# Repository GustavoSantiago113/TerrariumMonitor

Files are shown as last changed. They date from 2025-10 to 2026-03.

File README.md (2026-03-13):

<div align="center">

# 🌱 Tree Seedling Monitor

**An integration of ESP32-CAM with a custom HTTP API backend and Flutter to monitor tree seedling growth.**

</div>



---

## 📜 Table of Contents

- [🌱 Tree Seedling Monitor](#-tree-seedling-monitor)
  - [📜 Table of Contents](#-table-of-contents)
  - [💵 Bill of Materials](#-bill-of-materials)
  - [🎯 Objective](#-objective)
  - [🔗 Workflow](#-workflow)
  - [🔌 ESP32](#-esp32)
    - [⚙️ Configuration](#️-configuration)
    - [🧠 Pseudo-code](#-pseudo-code)
  - [🔙 API Backend](#-api-backend)
    - [🛜 API Endpoint](#-api-endpoint)
    - [🔓 Authentication](#-authentication)
      - [📨 Request Format](#-request-format)
      - [📤 Example Request](#-example-request)
      - [📥 Response](#-response)
      - [📝 Backend Implementation Notes](#-backend-implementation-notes)
  - [📱 App](#-app)
  - [⚡ PCB](#-pcb)
  - [📂 3D Files](#-3d-files)

## 💵 Bill of Materials

| Item | Quantity | Price |
| ---- | --- | ----- |
| Acrilic Case | 1 | 19 |
| Heater | 2 | 3 |
| AHT10 | 1 | 1.5 |
| Exhausting fan | 1 | 5.35 |
| PCB | 1 | 0.4 |
| ESP32CAM | 1 | 17 |
| Purple LED | 1 | 2.5 |
| 3D Printings | 1 | 1 |
| 5V Font | 1 | 5.39 |
| Wires and Connections | Many | 0.26 |
| | **Total** | 55 |

## 🎯 Objective

Build a tree seedling monitoring structure with image and sensor-based data monitoring and environment automation. The image and sensor-based data is sent to a custom HTTP API backend and retrieved by a mobile app. The sensor-based data is used to turn on exhausting fans and LEDs. MOTOR2 is configured as a heater output (see ESP32 section).

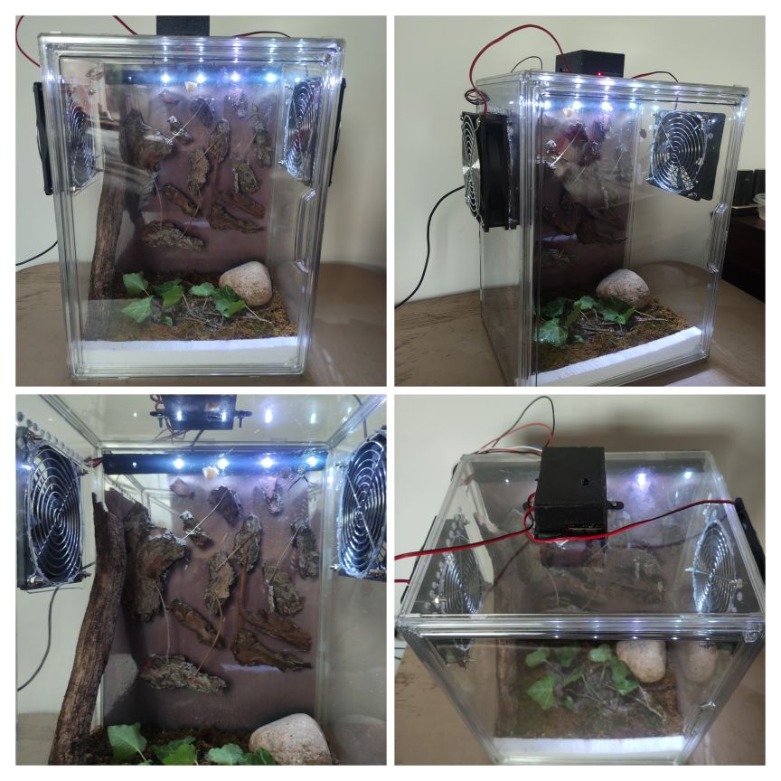
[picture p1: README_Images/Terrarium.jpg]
Terrarium


## 🔗 Workflow

The workflow works as depicted in the picture below.

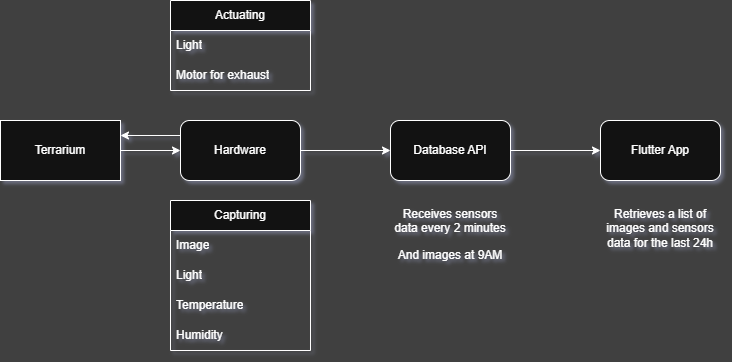
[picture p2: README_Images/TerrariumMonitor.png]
Workflow


The ESP32 captures temperature, air humidity, and light every 2 minutes. If the temperature or humidity exceeds the set threshold, the exhaust fans are activated. If the light is below the set threshold, the LEDs are turned on. After this, the data is sent to a custom HTTP API backend. Every day, at 9 AM and 4 PM, the image is captured, and all the data is uploaded to the backend.

The backend API (running at `********`) receives multipart form data containing:
- Timestamp
- Light intensity (lux)
- Temperature (°C)
- Humidity (%)
- JPEG image file

The API is secured with an API key (`*********` header). The backend stores the images and sensor data, making them available for the mobile app.

A Flutter-based app retrieves the images and sensor-based data from the API and displays it in the screen in form of image and graphs.

## 🔌 ESP32

The final code for the ESP32-CAM is in this [folder](ESP32/terrariumMonitor/). I split the actuators and sensors to make it more organized. All the sensitive information is on `secrets.h` (which I obviously did not push to Git). 

### ⚙️ Configuration

In `secrets.h`, define:
```cpp
#define WIFI_SSID "your_wifi_ssid"
#define WIFI_PASSWORD "your_wifi_password"
```

The API endpoint and key are configured directly in the main sketch:
```cpp
const char* API_ENDPOINT = "***********";
const char* API_KEY_HEADER = "*********";
const char* API_KEY_VALUE = "****************";
```

### 🧠 Pseudo-code

``` bash

INCLUDE required libraries (Arduino, WiFi, HTTPClient, Camera, LittleFS, Sensors)

DEFINE camera pin assignments

CONFIGURE API endpoint and authentication
    - API URL: ***********
    - API Key header: *********
    - API Key value: ****************

SETUP timing variables for periodic data sending (2 minutes)

DECLARE variables for sensor readings (lux, temperature, humidity)

DECLARE function prototypes

FUNCTION setup():
    Start serial communication
    Print startup message
    Test actuators (LEDs and motors)
    Initialize WiFi and wait for connection
    Configure time via NTP
    Initialize camera with optimal settings
    Initialize LittleFS filesystem
    Initialize sensors (light, temperature, humidity)
    Print setup complete

FUNCTION loop():
    IF 2 minutes have passed:
        
        Read sensors (lux, temp, humidity)
        Print sensor values
        Control actuators based on sensor thresholds
        Get current timestamp (via NTP or uptime fallbacks
        Send data to API via HTTP POST multipart/form-data:
            - timestamp
            - lux value
            - temperature value
            - humidity value
        IF upload successful:
            Print success message
        ELSE:
            Print error message
    IF 9 AM or 4 PM:
        Delete previous image file if it exists
        Capture photo and save to LittleFS with timestamp filename
        Send data to API via HTTP POST multipart/form-data:
            - timestamp
            - lux value
            - temperature value
            - humidity value
            - image file (JPEG)
        IF upload successful:
            Delete local image file to free space
            Print success message
        ELSE:
            Print error message
FUNCTION capturePhotoSaveLittleFS(photoPath):
    Flush camera buffer (3 warmup captures)
    Capture photo
    IF capture failed: print error and return
    Print photo file name
    Ensure parent directory exists (create if needed)
    Open file for writing
    IF file open failed: print error and return
    Write photo data to file, flush, and close
    Print file saved message with size
    Verify file exists and size matches written bytes
    IF verification passed: print success
    ELSE: print warning

FUNCTION initLittleFS():
    Mount LittleFS with format option, restart if failed

FUNCTION initWiFi():
    Connect to WiFi with credentials from secrets.h
    Wait for connection, print status and IP address

FUNCTION initCamera():
    Configure camera settings (pins, resolution, quality)
    IF PSRAM detected: use UXGA resolution
    ELSE: use SVGA resolution
    Initialize camera, restart if failed
    Configure sensor parameters (brightness, contrast, exposure, etc.)
    Print camera initialized message

FUNCTION sendDataToAPI(imagePath, lux, temp, humi, timestamp):
    Open image file from LittleFS
    IF file open failed: return false
    Initialize HTTP client with API endpoint
    Add API key header
    Generate random boundary for multipart form data
    Build multipart body with:
        - Form field: timestamp
        - Form field: lux
        - Form field: temperature
        - Form field: humidity
        - Form field: image (binary JPEG data)
    Send HTTP POST request manually:
        - Send headers (Host, *********, Content-Type, Content-Length)
        - Send form fields
        - Stream image file in 512-byte chunks with progress logging
        - Send closing boundary
    Wait for server response (10s timeout)
    Parse HTTP response code
    IF code is 200 or 201: return true (success)
    ELSE: print error and return false

```

## 🔙 API Backend

The system uses a custom HTTP API backend running at `********`.

### 🛜 API Endpoint

**POST** `/api/upload`

### 🔓 Authentication
Requests must include the `*********` header with value: `************************************`

#### 📨 Request Format
Content-Type: `multipart/form-data`

**Form fields:**
- `timestamp` - Unix timestamp of the data collection
- `lux` - Light intensity in lux (float)
- `temperature` - Temperature in Celsius (float)
- `humidity` - Humidity percentage (float)
- `image` - JPEG image file

#### 📤 Example Request
```http
POST /api/upload HTTP/1.1
Host: 10.0.0.50:8080
*********: ************************************
Content-Type: multipart/form-data; boundary=----WebKitFormBoundaryXYZ

------WebKitFormBoundaryXYZ
Content-Disposition: form-data; name="timestamp"

1700000000
------WebKitFormBoundaryXYZ
Content-Disposition: form-data; name="lux"

450.50
------WebKitFormBoundaryXYZ
Content-Disposition: form-data; name="temperature"

24.50
------WebKitFormBoundaryXYZ
Content-Disposition: form-data; name="humidity"

65.30
------WebKitFormBoundaryXYZ
Content-Disposition: form-data; name="image"; filename="1700000000.jpg"
Content-Type: image/jpeg

[binary image data]
------WebKitFormBoundaryXYZ--
```

#### 📥 Response
- **200 OK** or **201 Created** - Data successfully received and stored
- **401 Unauthorized** - Invalid or missing API key
- **400 Bad Request** - Invalid form data

#### 📝 Backend Implementation Notes
The backend should:
- Validate the API key
- Parse multipart form data
- Store images with timestamp-based filenames
- Store sensor readings in a database (linked by timestamp)
- Optionally implement data retention policies (e.g., delete data when the image folder exceeds 10GB)

## 📱 App

The App was made using Flutter and deployed locally. It retrieves all the readings and images from the custom API backend. The last image and data is shown on the screen. All the data is used to plot line graphs. The 8 most recent images are shown on the screen. If the user wants to see more, they click "See More" and 8 more will appear.

The app communicates with the backend API to:
- Retrieve images with their associated timestamps and sensor data
- Display historical data (24h) in graph format

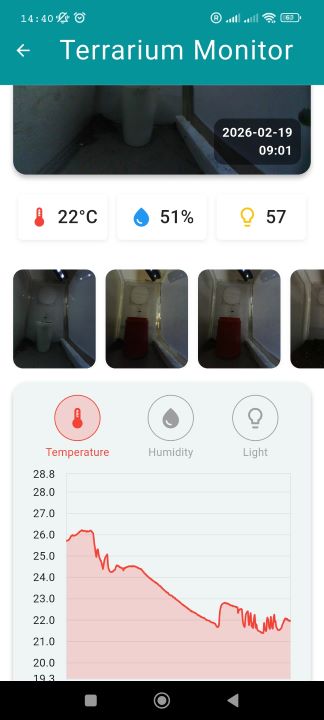
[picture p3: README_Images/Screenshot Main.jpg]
Main Page


When clicking on past images, the image will pop-up and be shown bigger on the screen, with the Date and Time, and data measured at the same time.

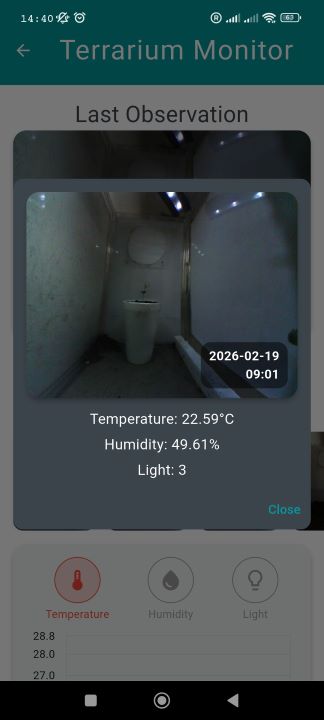
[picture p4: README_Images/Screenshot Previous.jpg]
Previous Data


## ⚡ PCB

Under the [PCB](PCB) folder, you can find the schematics, gerber file and PCB layout for the PCB. I used a simple circuit with transistor, diode and resistor to activate and deactivate the LED and exhausting fans.

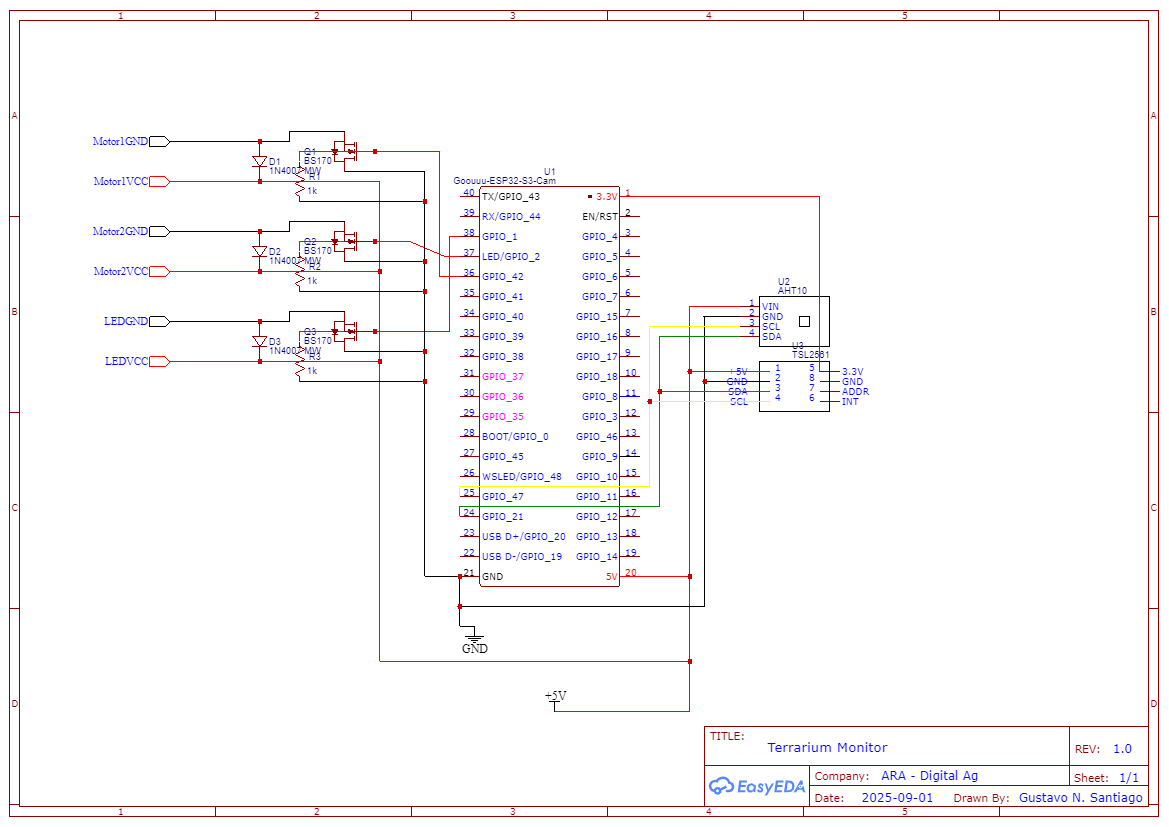
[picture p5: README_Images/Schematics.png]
Schematics


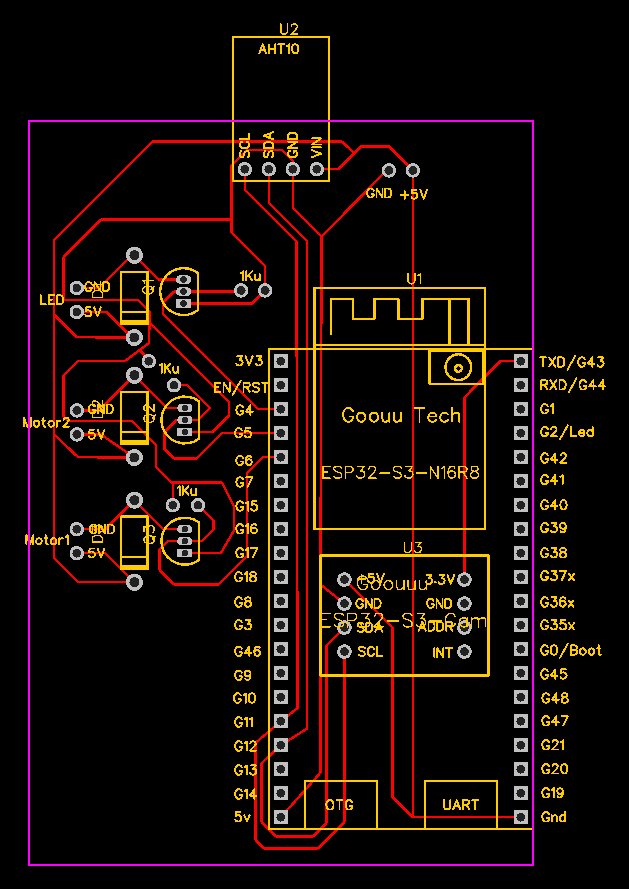
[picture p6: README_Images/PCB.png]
PCB


## 📂 3D Files

Under the [3D Files](3DFiles) folder, you can find all the necessary files to print the case for the PCB and the LEDs/AHT10 sensor encasing.

**PCB Case:**

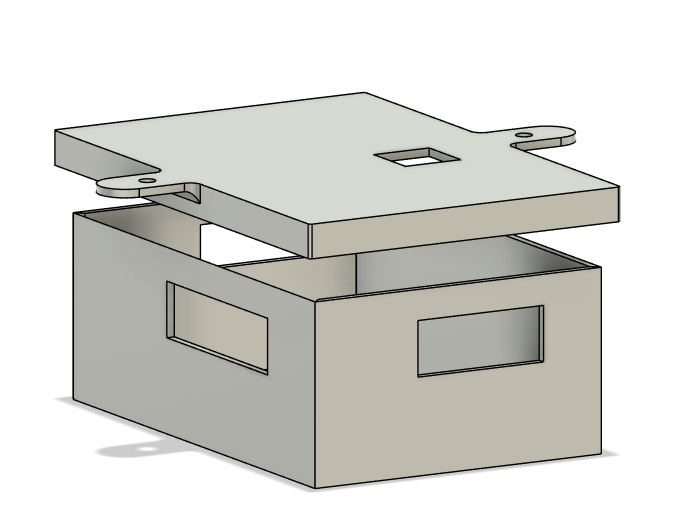
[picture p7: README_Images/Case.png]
PCB Case


**Sensors Case:**

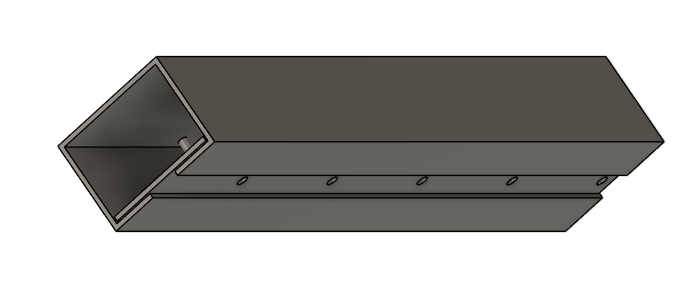
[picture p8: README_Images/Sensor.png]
Sensors Case


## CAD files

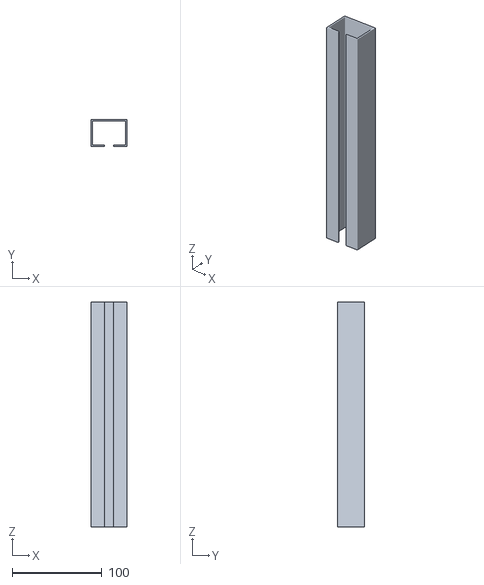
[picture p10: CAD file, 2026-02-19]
3DFIles/LED Cover.stl
40.0 x 30.0 x 250.0

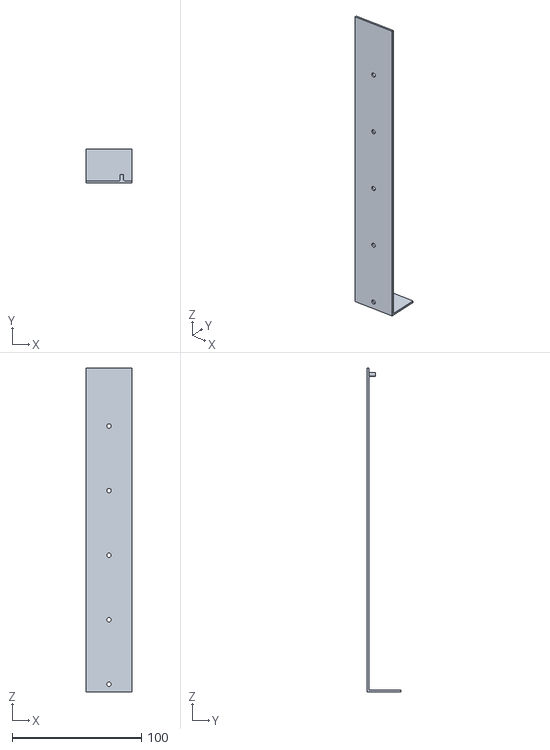
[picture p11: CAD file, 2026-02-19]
3DFIles/LED Base.stl
36.0 x 26.0 x 251.0

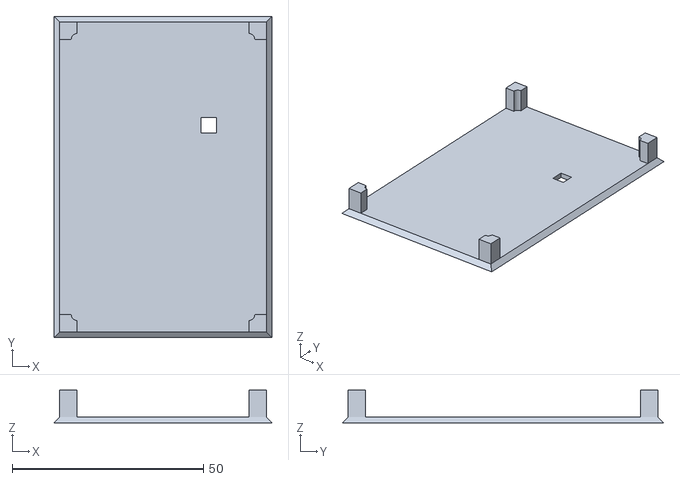
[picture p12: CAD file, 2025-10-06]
3DFIles/Top.stl
57.0 x 84.0 x 8.50

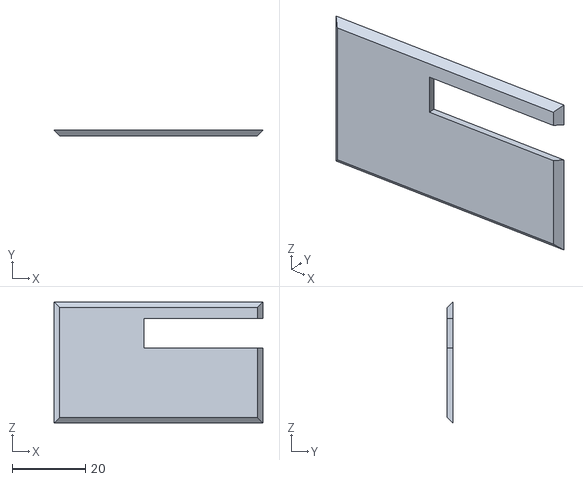
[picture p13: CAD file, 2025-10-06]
3DFIles/Front.stl
57.0 x 1.50 x 33.0

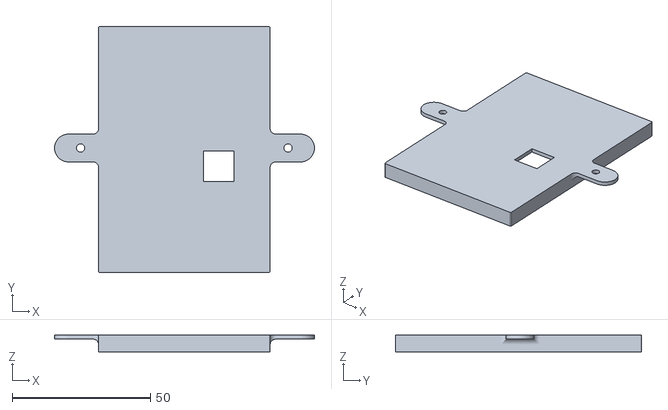
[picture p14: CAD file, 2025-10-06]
3DFIles/Bottom.stl
94.0 x 89.0 x 6.13

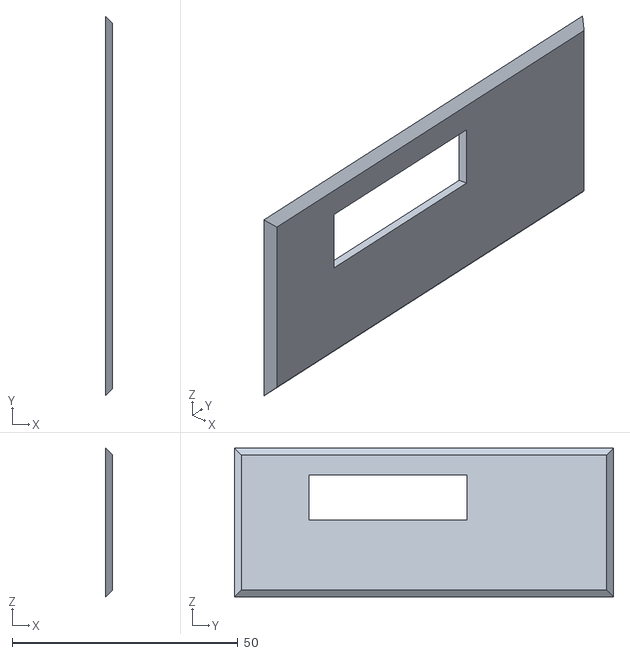
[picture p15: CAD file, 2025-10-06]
3DFIles/Right.stl
1.50 x 84.0 x 33.0

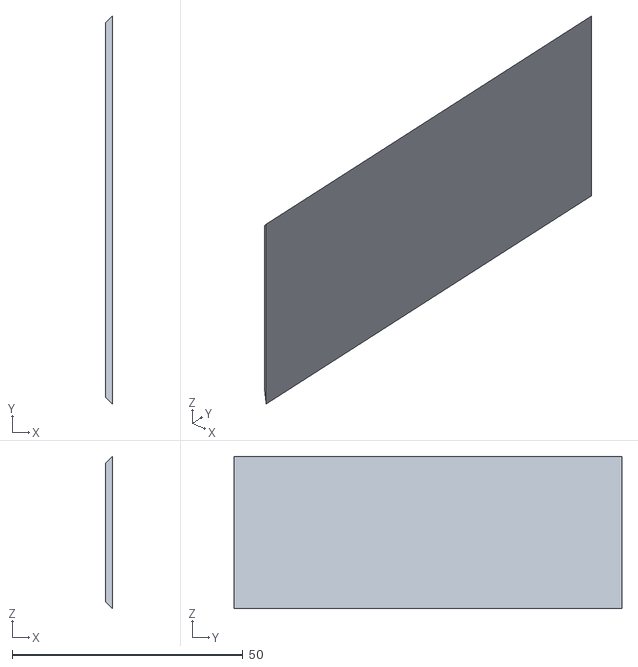
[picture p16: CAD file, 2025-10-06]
3DFIles/Left.stl
1.50 x 84.0 x 33.0

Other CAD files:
3DFIles/Back.stl

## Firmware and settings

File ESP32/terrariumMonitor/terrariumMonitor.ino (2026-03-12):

#include <Arduino.h>
#include <FS.h>
#include <LittleFS.h>
#include <WiFi.h>
#include <HTTPClient.h>
#include "esp_camera.h"
#include <Wire.h>
#include "secrets.h"
#include "sensors.h"
#include "actuators.h"

// ==== Camera Pins ====
#define PWDN_GPIO_NUM  -1
#define RESET_GPIO_NUM -1
#define XCLK_GPIO_NUM  15
#define SIOD_GPIO_NUM  4
#define SIOC_GPIO_NUM  5
#define Y2_GPIO_NUM 11
#define Y3_GPIO_NUM 9
#define Y4_GPIO_NUM 8
#define Y5_GPIO_NUM 10
#define Y6_GPIO_NUM 12
#define Y7_GPIO_NUM 18
#define Y8_GPIO_NUM 17
#define Y9_GPIO_NUM 16
#define VSYNC_GPIO_NUM 6
#define HREF_GPIO_NUM  7
#define PCLK_GPIO_NUM  13
#define LED_GPIO_NUM -1

// ==== API and WiFi Configuration in secrets.h ====

// ==== Timing ====
unsigned long lastDataMillis = 0;
const unsigned long sendInterval = 2 * 60 * 1000; // 2 minutes

// Track last scheduled upload to avoid duplicate uploads within the same hour/day
int lastUploadDay = -1;
int lastUploadHour = -1;

// ==== Sensor Values ====
float lastLux = 0;
float lastTemp = 0;
float lastHumi = 0;

// ==== Function Prototypes ====
void capturePhotoSaveLittleFS(const String &photoPath);
void initLittleFS();
void initWiFi();
void initCamera();
bool sendDataToAPI(const String &imagePath, float lux, float temp, float humi, time_t timestamp);
size_t fsTotalBytes();
size_t fsUsedBytes();
size_t fsFreeBytes();
void printFSInfo(const char *tag = "FS");
void deleteAllJpgFiles();
bool ensureFsFree(size_t minFreeBytes);
void ensureWiFiConnected();

// ==== File System ====
String uniquePath = "";

// ==== Setup ====
void setup() {
  Serial.begin(115200);
  Serial.println("Starting ESP32-S3-CAM + Sensor System...");
  
  pinMode(LED_BUILTIN, OUTPUT); // Built-in LED for error indication
  digitalWrite(LED_BUILTIN, LOW); // Turn off LED initially

  // Test motors and lights
  Serial.println("Testing motors and lights...");
  pinMode(LED_PIN, OUTPUT);
  pinMode(MOTOR1_PIN, OUTPUT);
  pinMode(MOTOR2_PIN, OUTPUT);

  digitalWrite(LED_PIN, HIGH);
  delay(500);
  digitalWrite(LED_PIN, LOW);
  delay(500);

  digitalWrite(MOTOR1_PIN, HIGH);
  delay(500);
  digitalWrite(MOTOR1_PIN, LOW);
  delay(500);

  digitalWrite(MOTOR2_PIN, HIGH);
  delay(500);
  digitalWrite(MOTOR2_PIN, LOW);
  delay(500);

  Serial.println("Motors and lights tested successfully.");

  // Initialize WiFi
  Serial.println("Connecting to WiFi...");
  initWiFi();
  if (WiFi.status() != WL_CONNECTED) {
    Serial.println("WiFi connection failed!");
    digitalWrite(LED_BUILTIN, HIGH); // Turn on error LED
    while (true) delay(1000); // Halt execution
  }
  Serial.println("WiFi connected!");

  // Configure time
  configTime(-5 * 3600, 3600, "pool.ntp.org", "time.nist.gov");

  // Initialize camera
  Serial.println("Initializing camera...");
  initCamera();
  if (!esp_camera_sensor_get()) {
    Serial.println("Camera initialization failed!");
    digitalWrite(LED_BUILTIN, HIGH); // Turn on error LED
    while (true) delay(1000); // Halt execution
  }
  Serial.println("Camera initialized successfully.");

  // Initialize LittleFS
  Serial.println("Initializing LittleFS...");
  initLittleFS();
  printFSInfo("Boot");
  // Make sure we have enough headroom before first capture
  // Target at least ~300KB free to accommodate a VGA/low-quality JPEG
  if (!ensureFsFree(300 * 1024)) {
    Serial.println("Warning: Not enough free FS space even after cleanup.");
  }

  // Initialize sensors
  Serial.println("Initializing sensors...");
  initSensors();

  Serial.println("Setup complete!");
}

// ==== Main Loop ====
void loop() {
  // Every 2 minutes, send data and image
  if (millis() - lastDataMillis >= sendInterval) {
    // Proactively ensure some free space for regular operation
    ensureFsFree(250 * 1024);

    // Monitor sensors
    Serial.println("Reading sensors...");
    readSensors(lastLux, lastTemp, lastHumi);
    Serial.print("✓ Light: ");
    Serial.print(lastLux);
    Serial.println(" lux");
    Serial.print("✓ Temperature: ");
    Serial.print(lastTemp);
    Serial.print("°C, Humidity: ");
    Serial.print(lastHumi);
    Serial.println("%");

    // Ensure WiFi connectivity before any network operations
    ensureWiFiConnected();

    // Actuate as before
    controlActuators(lastLux, lastTemp, lastHumi);

    lastDataMillis = millis();

    // Get current timestamp / local time
    time_t now;
    struct tm timeinfo;
    bool haveTime = getLocalTime(&timeinfo);
    if (haveTime) {
      now = mktime(&timeinfo);
    } else {
      now = millis() / 1000; // Fallback to uptime if NTP fails
    }

    // Decide whether to capture image locally: only at ~9:00 and ~16:00 once per day
    bool shouldCapture = false;
    if (haveTime) {
      int currentHour = timeinfo.tm_hour;
      int currentMin = timeinfo.tm_min;
      int intervalMin = (int)(sendInterval / 60000);
      if ((currentHour == 9 || currentHour == 16) && currentMin < intervalMin) {
        if (!(lastUploadDay == timeinfo.tm_mday && lastUploadHour == currentHour)) {
          shouldCapture = true;
          lastUploadDay = timeinfo.tm_mday;
          lastUploadHour = currentHour;
        }
      }
    }

    if (shouldCapture) {
      Serial.println("Scheduled time reached — capturing photo and uploading image+data...");
      // Delete old image if it exists
      if (uniquePath.length() > 0 && LittleFS.exists(uniquePath)) {
        Serial.println("Deleting old image...");
        if (LittleFS.remove(uniquePath)) {
          Serial.print("Successfully deleted: ");
          Serial.println(uniquePath);
        } else {
          Serial.print("Failed to delete: ");
          Serial.println(uniquePath);
        }
      }

      uniquePath = "/" + String(now) + ".jpg";
      // Turn on light before photo
      Serial.println("Turning on light for photo...");
      digitalWrite(LED_PIN, HIGH);
      delay(300); // allow light to stabilize
      capturePhotoSaveLittleFS(uniquePath);
      // Turn off light after photo
      digitalWrite(LED_PIN, LOW);
      Serial.println("Light turned off after photo.");

      // Upload image + data
      Serial.println("Sending image+data to API...");
      if (sendDataToAPI(uniquePath, lastLux, lastTemp, lastHumi, now)) {
        Serial.println("✅ Image+data upload successful");
      } else {
        Serial.println("❌ Image+data upload failed");
      }

      // Remove local image after upload
      if (LittleFS.remove(uniquePath)) {
        Serial.println("Image deleted.");
        uniquePath = "";
      }
      printFSInfo("PostUpload");
    } else {
      // Not capture time: upload data-only
      Serial.println("Uploading sensor data (no image)...");
      if (sendSensorDataToAPI(lastLux, lastTemp, lastHumi, now)) {
        Serial.println("✅ Data-only upload successful");
      } else {
        Serial.println("❌ Data-only upload failed");
      }

      Serial.println("Not capture time — skipping photo.");
      printFSInfo("NoCaptureCycle");
    }
  }
}

// ==== Camera and File System Functions ====
void capturePhotoSaveLittleFS(const String &photoPath) {
  camera_fb_t* fb = NULL;
  for (int i = 0; i < 3; i++) {
    fb = esp_camera_fb_get();
    if (fb) {
      esp_camera_fb_return(fb);
      fb = NULL;
    }
    delay(100);
  }

  fb = esp_camera_fb_get();
  if (!fb) {
    Serial.println("Camera capture failed");
    return;
  }

  Serial.printf("Picture file name: %s\n", photoPath.c_str());

  // ensure parent directory exists
  int slash = photoPath.lastIndexOf('/');
  String dir = (slash > 0) ? photoPath.substring(0, slash) : String("/");
  if (dir.length() > 1 && !LittleFS.exists(dir)) {
    Serial.print("Creating directory: ");
    Serial.println(dir);
    if (!LittleFS.mkdir(dir)) {
      Serial.print("Failed to create directory: ");
      Serial.println(dir);
      // fall back to root filename
    } else {
      Serial.println("Directory created");
    }
  }

  File file = LittleFS.open(photoPath, FILE_WRITE);
  if (!file) {
    Serial.println("Failed to open file in writing mode - aborting save");
    esp_camera_fb_return(fb);
    return;
  }

  // write, flush and close to ensure content is fully committed to LittleFS
  size_t written = file.write(fb->buf, fb->len);
  file.flush();
  file.close();

  Serial.print("The picture has been saved in ");
  Serial.print(photoPath);
  Serial.print(" - Size written: ");
  Serial.print(written);
  Serial.print(" bytes (fb len: ");
  Serial.print(fb->len);
  Serial.println(")");

  esp_camera_fb_return(fb);
  delay(100);

  // verify file exists and size matches before setting media_file
  if (LittleFS.exists(photoPath)) {
    File check = LittleFS.open(photoPath, "r");
    if (check) {
      size_t sz = check.size();
      check.close();
      if (sz == written && written > 0) {
        Serial.print("Photo saved successfully: ");
        Serial.println(photoPath);
        return;
      }
      Serial.printf("Warning: written %u bytes but file size is %u\n", (unsigned)written, (unsigned)sz);
    } else {
      Serial.println("Warning: unable to open file for verification");
    }
  } else {
    Serial.println("Warning: file does not exist after write");
  }

  // fallback: do not update media_file if verification failed
  Serial.println("Capture saved but media_file not updated due to verification failure.");
}

void initLittleFS() {
  if (!LittleFS.begin(true)) {
    Serial.println("An Error has occurred while mounting LittleFS");
    ESP.restart();
  } else {
    Serial.println("LittleFS mounted successfully");
  }
}

void initWiFi() {
  WiFi.begin(WIFI_SSID, WIFI_PASSWORD);
  Serial.print("Connecting to WiFi");
  while (WiFi.status() != WL_CONNECTED) {
    delay(1000);
    Serial.print(".");
  }
  Serial.println();
  Serial.println("WiFi connected!");
  Serial.print("IP address: ");
  Serial.println(WiFi.localIP());
}

// Ensure WiFi is connected; attempt reconnect if disconnected
void ensureWiFiConnected() {
  if (WiFi.status() == WL_CONNECTED) return;
  Serial.println("WiFi disconnected — attempting reconnect...");
  WiFi.disconnect(true);
  WiFi.reconnect();
  unsigned long start = millis();
  const unsigned long timeout = 15000;
  while (WiFi.status() != WL_CONNECTED && (millis() - start) < timeout) {
    Serial.print(".");
    delay(500);
  }
  if (WiFi.status() == WL_CONNECTED) {
    Serial.println("\nWiFi reconnected!");
    Serial.print("IP address: ");
    Serial.println(WiFi.localIP());
  } else {
    Serial.println("\nWiFi reconnect failed (will retry next cycle)");
  }
}

void initCamera() {
  camera_config_t config;
  config.ledc_channel = LEDC_CHANNEL_0;
  config.ledc_timer = LEDC_TIMER_0;
  config.pin_d0 = Y2_GPIO_NUM;
  config.pin_d1 = Y3_GPIO_NUM;
  config.pin_d2 = Y4_GPIO_NUM;
  config.pin_d3 = Y5_GPIO_NUM;
  config.pin_d4 = Y6_GPIO_NUM;
  config.pin_d5 = Y7_GPIO_NUM;
  config.pin_d6 = Y8_GPIO_NUM;
  config.pin_d7 = Y9_GPIO_NUM;
  config.pin_xclk = XCLK_GPIO_NUM;
  config.pin_pclk = PCLK_GPIO_NUM;
  config.pin_vsync = VSYNC_GPIO_NUM;
  config.pin_href = HREF_GPIO_NUM;
  config.pin_sccb_sda = SIOD_GPIO_NUM;
  config.pin_sccb_scl = SIOC_GPIO_NUM;
  config.pin_pwdn = PWDN_GPIO_NUM;
  config.pin_reset = RESET_GPIO_NUM;
  config.xclk_freq_hz = 20000000;
  config.pixel_format = PIXFORMAT_JPEG;
  config.grab_mode = CAMERA_GRAB_LATEST;
  
  if (psramFound()) {
    config.frame_size = FRAMESIZE_UXGA;
    config.jpeg_quality = 12;
    config.fb_count = 1;
  } else {
    config.frame_size = FRAMESIZE_SVGA;
    config.jpeg_quality = 12;
    config.fb_count = 1;
  }
  
  esp_err_t err = esp_camera_init(&config);
  if (err != ESP_OK) {
    Serial.printf("Camera init failed with error 0x%x", err);
    ESP.restart();
  }
  
  // Camera settings
  sensor_t * s = esp_camera_sensor_get();
  s->set_brightness(s, 1); // Increased brightness (range: -2 to 2)
  s->set_contrast(s, 0.5);
  s->set_saturation(s, 0.5);
  s->set_special_effect(s, 0);
  s->set_whitebal(s, 1);
  s->set_awb_gain(s, 1);
  s->set_wb_mode(s, 0);
  s->set_exposure_ctrl(s, 1);
  s->set_aec2(s, 0);
  s->set_ae_level(s, 0);
  s->set_aec_value(s, 300);
  s->set_gain_ctrl(s, 1);
  s->set_agc_gain(s, 0);
  s->set_gainceiling(s, (gainceiling_t)0);
  s->set_bpc(s, 0);
  s->set_wpc(s, 1);
  s->set_raw_gma(s, 1);
  s->set_lenc(s, 1);
  s->set_hmirror(s, 0);
  s->set_vflip(s, 0);
  s->set_dcw(s, 1);
  s->set_colorbar(s, 0);
  
  Serial.println("Camera initialized successfully");
}

// ==== FS Utilities ====
size_t fsTotalBytes() {
  return LittleFS.totalBytes();
}

size_t fsUsedBytes() {
  return LittleFS.usedBytes();
}

size_t fsFreeBytes() {
  size_t total = fsTotalBytes();
  size_t used = fsUsedBytes();
  return (total > used) ? (total - used) : 0;
}

void printFSInfo(const char *tag) {
  size_t total = fsTotalBytes();
  size_t used = fsUsedBytes();
  size_t freeB = (total > used) ? (total - used) : 0;
  Serial.printf("[%s] LittleFS - Total: %u bytes, Used: %u bytes, Free: %u bytes\n", tag, (unsigned)total, (unsigned)used, (unsigned)freeB);
}

void deleteAllJpgFiles() {
  Serial.println("Cleaning up .jpg files in LittleFS...");
  File root = LittleFS.open("/");
  if (!root) {
    Serial.println("Failed to open root directory for cleanup");
    return;
  }
  File file = root.openNextFile();
  int removed = 0;
  while (file) {
    String name = file.name();
    if (!name.startsWith("/")) name = String("/") + name; // normalize path
    file.close();
    if (name.endsWith(".jpg")) {
      if (LittleFS.remove(name)) {
        removed++;
        Serial.print("Removed: ");
        Serial.println(name);
      } else {
        Serial.print("Failed to remove: ");
        Serial.println(name);
      }
    }
    file = root.openNextFile();
  }
  root.close();
  Serial.printf("Cleanup complete. Files removed: %d\n", removed);
}

bool ensureFsFree(size_t minFreeBytes) {
  size_t freeB = fsFreeBytes();
  if (freeB >= minFreeBytes) {
    return true;
  }
  Serial.printf("Free space low (%u bytes). Target: %u. Attempting cleanup...\n", (unsigned)freeB, (unsigned)minFreeBytes);
  deleteAllJpgFiles();
  freeB = fsFreeBytes();
  printFSInfo("AfterCleanup");
  return freeB >= minFreeBytes;
}

// ==== Data-only API Upload Function ====
bool sendSensorDataToAPI(float lux, float temp, float humi, time_t timestamp) {
  HTTPClient http;
  http.begin(API_ENDPOINT);
  http.addHeader(API_KEY_HEADER, API_KEY_VALUE);

  // Use multipart/form-data to remain compatible with server expecting form fields
  String boundary = "----WebKitFormBoundary" + String(random(0xffff), HEX);
  http.addHeader("Content-Type", "multipart/form-data; boundary=" + boundary);

  String body = "";
  body += "--" + boundary + "\r\n";
  body += "Content-Disposition: form-data; name=\"timestamp\"\r\n\r\n";
  body += String(timestamp) + "\r\n";

  body += "--" + boundary + "\r\n";
  body += "Content-Disposition: form-data; name=\"luminosity\"\r\n\r\n";
  body += String(lux, 2) + "\r\n";

  body += "--" + boundary + "\r\n";
  body += "Content-Disposition: form-data; name=\"temperature\"\r\n\r\n";
  body += String(temp, 2) + "\r\n";

  body += "--" + boundary + "\r\n";
  body += "Content-Disposition: form-data; name=\"humidity\"\r\n\r\n";
  body += String(humi, 2) + "\r\n";

  body += "--" + boundary + "--\r\n";

  http.setTimeout(15000);
  int httpCode = http.POST(body);
  if (httpCode > 0) {
    Serial.printf("HTTP Response code (data-only): %d\n", httpCode);
    String response = http.getString();
    Serial.println("Response: " + response);
    http.end();
    return (httpCode == 200 || httpCode == 201);
  } else {
    Serial.printf("HTTP request failed (data-only), error: %s\n", http.errorToString(httpCode).c_str());
    http.end();
    return false;
  }
}

// ==== API Upload Function ====
bool sendDataToAPI(const String &imagePath, float lux, float temp, float humi, time_t timestamp) {
  if (!LittleFS.exists(imagePath)) {
    Serial.println("Image file does not exist!");
    return false;
  }

  File imageFile = LittleFS.open(imagePath, "r");
  if (!imageFile) {
    Serial.println("Failed to open image file!");
    return false;
  }

  size_t fileSize = imageFile.size();
  Serial.printf("Image size: %u bytes\n", (unsigned)fileSize);

  HTTPClient http;
  http.begin(API_ENDPOINT);
  http.addHeader(API_KEY_HEADER, API_KEY_VALUE);

  // Generate boundary for multipart/form-data
  String boundary = "----WebKitFormBoundary" + String(random(0xffff), HEX);
  http.addHeader("Content-Type", "multipart/form-data; boundary=" + boundary);

  // Build multipart form data body
  String bodyStart = "";
  
  // Add timestamp field
  bodyStart += "--" + boundary + "\r\n";
  bodyStart += "Content-Disposition: form-data; name=\"timestamp\"\r\n\r\n";
  bodyStart += String(timestamp) + "\r\n";
  
  // Add luminosity field
  bodyStart += "--" + boundary + "\r\n";
  bodyStart += "Content-Disposition: form-data; name=\"luminosity\"\r\n\r\n";
  bodyStart += String(lux, 2) + "\r\n";
  
  // Add temperature field
  bodyStart += "--" + boundary + "\r\n";
  bodyStart += "Content-Disposition: form-data; name=\"temperature\"\r\n\r\n";
  bodyStart += String(temp, 2) + "\r\n";
  
  // Add humidity field
  bodyStart += "--" + boundary + "\r\n";
  bodyStart += "Content-Disposition: form-data; name=\"humidity\"\r\n\r\n";
  bodyStart += String(humi, 2) + "\r\n";
  
  // Add image field header
  bodyStart += "--" + boundary + "\r\n";
  bodyStart += "Content-Disposition: form-data; name=\"images\"; filename=\"" + String(timestamp) + ".jpg\"\r\n";
  bodyStart += "Content-Type: image/jpeg\r\n\r\n";
  
  String bodyEnd = "\r\n--" + boundary + "--\r\n";
  
  // Build complete multipart body
  String completeBody = bodyStart;
  
  // Read image data and append to body
  uint8_t buffer[1024];
  while (imageFile.available()) {
    size_t bytesRead = imageFile.read(buffer, sizeof(buffer));
    for (size_t i = 0; i < bytesRead; i++) {
      completeBody += (char)buffer[i];
    }
  }
  imageFile.close();
  
  // Append body end
  completeBody += bodyEnd;
  
  Serial.printf("Total payload size: %u bytes\n", completeBody.length());
  
  // Set timeout
  http.setTimeout(30000); // 30 seconds
  
  // Send POST request
  int httpCode = http.POST(completeBody);
  
  if (httpCode > 0) {
    Serial.printf("HTTP Response code: %d\n", httpCode);
    String response = http.getString();
    Serial.println("Response: " + response);
    http.end();
    return (httpCode == 200 || httpCode == 201);
  } else {
    Serial.printf("HTTP request failed, error: %s\n", http.errorToString(httpCode).c_str());
    http.end();
    return false;
  }
}

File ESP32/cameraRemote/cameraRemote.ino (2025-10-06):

#define ENABLE_USER_AUTH
#define ENABLE_STORAGE
#define ENABLE_FS

#include <Arduino.h>
#include <FirebaseClient.h>
#include <FS.h>
#include <LittleFS.h>
#include <WiFi.h>
#include <WiFiClientSecure.h>
#include "esp_camera.h"
#include "secrets.h"

// User functions
void processData(AsyncResult &aResult);
void file_operation_callback(File &file, const char *filename, file_operating_mode mode);

FileConfig media_file(FILE_PHOTO_PATH, file_operation_callback); // Can be set later with media_file.setFile("/image.png", file_operation_callback);

File myFile;

// Authentication
UserAuth user_auth(API_KEY, USER_EMAIL, USER_PASS, 3000 /* expire period in seconds (<3600) */);

static unsigned long lastPhotoMillis = 0;
const unsigned long photoInterval = 30000;

// Firebase components
FirebaseApp app;
WiFiClientSecure ssl_client;
using AsyncClient = AsyncClientClass;
AsyncClient aClient(ssl_client);
Storage storage;

bool taskComplete = false;

AsyncResult storageResult;

// OV2640 camera module pins (CAMERA_MODEL_AI_THINKER)
#define PWDN_GPIO_NUM  -1
#define RESET_GPIO_NUM -1
#define XCLK_GPIO_NUM  15
#define SIOD_GPIO_NUM  4
#define SIOC_GPIO_NUM  5

#define Y2_GPIO_NUM 11
#define Y3_GPIO_NUM 9
#define Y4_GPIO_NUM 8
#define Y5_GPIO_NUM 10
#define Y6_GPIO_NUM 12
#define Y7_GPIO_NUM 18
#define Y8_GPIO_NUM 17
#define Y9_GPIO_NUM 16

#define VSYNC_GPIO_NUM 6
#define HREF_GPIO_NUM  7
#define PCLK_GPIO_NUM  13

#define LED_GPIO_NUM -1

boolean takeNewPhoto = true;

// Capture Photo and Save it to LittleFS
void capturePhotoSaveLittleFS( void ) {
  // Dispose first pictures because of bad quality
  camera_fb_t* fb = NULL;
  // Skip first 3 frames (increase/decrease number as needed).
  for (int i = 0; i < 10; i++) {
    fb = esp_camera_fb_get();
    esp_camera_fb_return(fb);
    fb = NULL;
  }
    
  // Take a new photo
  fb = NULL;  
  fb = esp_camera_fb_get();  
  if(!fb) {
    Serial.println("Camera capture failed");
    delay(1000);
    ESP.restart();
  }  

  // Photo file name
  Serial.printf("Picture file name: %s\n", FILE_PHOTO_PATH);
  File file = LittleFS.open(FILE_PHOTO_PATH, FILE_WRITE);

  // Insert the data in the photo file
  if (!file) {
    Serial.println("Failed to open file in writing mode");
  }
  else {
    file.write(fb->buf, fb->len); // payload (image), payload length
    Serial.print("The picture has been saved in ");
    Serial.print(FILE_PHOTO_PATH);
    Serial.print(" - Size: ");
    Serial.print(fb->len);
    Serial.println(" bytes");
  }
  // Close the file
  file.close();
  esp_camera_fb_return(fb);
  delay(100);
}

void initLittleFS(){
  if (!LittleFS.begin(true)) {
    Serial.println("An Error has occurred while mounting LittleFS");
    ESP.restart();
  }
  else {
    delay(500);
    Serial.println("LittleFS mounted successfully");
  }
}

void initWiFi(){
  WiFi.begin(WIFI_SSID, WIFI_PASSWORD);
  while (WiFi.status() != WL_CONNECTED) {
    delay(1000);
    Serial.println("Connecting to WiFi...");
  }
}

void initCamera(){
 // OV2640 camera module
  camera_config_t config;
  config.ledc_channel = LEDC_CHANNEL_0;
  config.ledc_timer = LEDC_TIMER_0;
  config.pin_d0 = Y2_GPIO_NUM;
  config.pin_d1 = Y3_GPIO_NUM;
  config.pin_d2 = Y4_GPIO_NUM;
  config.pin_d3 = Y5_GPIO_NUM;
  config.pin_d4 = Y6_GPIO_NUM;
  config.pin_d5 = Y7_GPIO_NUM;
  config.pin_d6 = Y8_GPIO_NUM;
  config.pin_d7 = Y9_GPIO_NUM;
  config.pin_xclk = XCLK_GPIO_NUM;
  config.pin_pclk = PCLK_GPIO_NUM;
  config.pin_vsync = VSYNC_GPIO_NUM;
  config.pin_href = HREF_GPIO_NUM;
  config.pin_sccb_sda = SIOD_GPIO_NUM;
  config.pin_sccb_scl = SIOC_GPIO_NUM;
  config.pin_pwdn = PWDN_GPIO_NUM;
  config.pin_reset = RESET_GPIO_NUM;
  config.xclk_freq_hz = 20000000;
  config.pixel_format = PIXFORMAT_JPEG;
  config.grab_mode = CAMERA_GRAB_LATEST;

  if (psramFound()) {
    config.frame_size = FRAMESIZE_UXGA;
    config.jpeg_quality = 12;
    config.fb_count = 1;
  } else {
    config.frame_size = FRAMESIZE_SVGA;
    config.jpeg_quality = 12;
    config.fb_count = 1;
  }
  // Camera init
  esp_err_t err = esp_camera_init(&config);
  if (err != ESP_OK) {
    Serial.printf("Camera init failed with error 0x%x", err);
    ESP.restart();
  }
  Serial.println("Camera init success");
}

void setup(){
    Serial.begin(115200);
    initWiFi();
    initCamera();

    Firebase.printf("Firebase Client v%s\n", FIREBASE_CLIENT_VERSION);

    initLittleFS();

    // Configure SSL client
    ssl_client.setInsecure();
    ssl_client.setConnectionTimeout(1000);
    ssl_client.setHandshakeTimeout(5);
    Serial.println("Initializing app...");
    initializeApp(aClient, app, getAuth(user_auth), processData, "🔐 authTask");

    app.getApp<Storage>(storage);

    Serial.println("Listing files in LittleFS:");
    File root = LittleFS.open("/");
    File file = root.openNextFile();
    while (file) {
        Serial.println(file.name());
        file = root.openNextFile();
    }

}

String getUniquePhotoPath() {
    time_t now;
    struct tm timeinfo;
    if (!getLocalTime(&timeinfo)) {
        now = millis(); // fallback if RTC not set
    } else {
        now = mktime(&timeinfo);
    }

    return "/spider_monitor_images/photo_" + String(now) + ".jpg";
}

void loop(){
    // To maintain the authentication process.
    app.loop();

     if (app.ready() && (millis() - lastPhotoMillis >= photoInterval)) {
        lastPhotoMillis = millis();

        capturePhotoSaveLittleFS();

        // Generate a unique path for each upload
        String uniquePath = getUniquePhotoPath();

        // Async call with callback function.
        storage.upload(aClient, FirebaseStorage::Parent(STORAGE_BUCKET_ID, uniquePath.c_str()), getFile(media_file), "image/jpg", processData, "⬆️  uploadTask");
    }
}
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

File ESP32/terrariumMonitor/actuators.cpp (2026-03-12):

#include <Arduino.h>
#include "actuators.h"

void controlActuators(float lux, float temp, float humi) {
    struct tm timeinfo;
    getLocalTime(&timeinfo);
    int hour = timeinfo.tm_hour;

    // LED logic: If luminosity < 50 and between 7am and 7pm, turn LEDs on
    if (lux < 25 && hour >= 7 && hour < 19) {
        digitalWrite(LED_PIN, HIGH);
    } else {
        digitalWrite(LED_PIN, LOW);
    }

    // Motor1: exhaust fan control (unchanged behavior)
    if (temp > 33 || humi > 75) {
        digitalWrite(MOTOR1_PIN, HIGH);
    } else {
        digitalWrite(MOTOR1_PIN, LOW);
    }

    // Motor2: heater control with hysteresis
    static bool heaterOn = false;
    if (!heaterOn && temp <= HEATER_ON_TEMP) {
        heaterOn = true;
        digitalWrite(MOTOR2_PIN, HIGH);
        Serial.println("Heater turned ON (MOTOR2_PIN)");
    } else if (heaterOn && temp >= HEATER_OFF_TEMP) {
        heaterOn = false;
        digitalWrite(MOTOR2_PIN, LOW);
        Serial.println("Heater turned OFF (MOTOR2_PIN)");
    }
}

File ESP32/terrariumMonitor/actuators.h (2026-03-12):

#pragma once

#include <Arduino.h>

#define LED_PIN 1
#define MOTOR1_PIN 2
#define MOTOR2_PIN 42

// Heater thresholds (Celsius)
// MOTOR2_PIN is used as heater output. Heater turns ON at or below HEATER_ON_TEMP
// and turns OFF at or above HEATER_OFF_TEMP to provide hysteresis.
#define HEATER_ON_TEMP 26.0
#define HEATER_OFF_TEMP 33.0

void controlActuators(float lux, float temp, float humi);

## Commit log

2026-01-21 chore: uploading images only at 9am and 4pm
    [partitions.csv]
2026-02-19 3D FIles and images uploaded
    [Case.stl, LED Base.stl, LED Cover.stl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]
2026-02-26 Rename project to Tree Seedling Monitor
    Updated project name and description to reflect tree seedling monitoring. Revised the list of materials to Bill of Materials.
2026-03-12 update readme, adding heater and wifi reconection
